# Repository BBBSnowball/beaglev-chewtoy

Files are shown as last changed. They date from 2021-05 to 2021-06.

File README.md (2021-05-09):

This is a fairly simple little board targetted at the BeagleV, but likely usable for anything that uses a 2x20 pin header.

The board takes the existing 2x20 header and either via a through-hole, or smt, header extends it away from the board
(assuming the connector is on the edge), and rotates it 180deg so if you happen to have a large heat sink, or something
else that's blocking the pins they might still be accessible for hats, etc. Most pre-production beta BeagleV boards have a
large heatsink out of an abundance of caution but this is not required and won't be used for production units.

This fork adds:
- LEDs: They are behind a buffer so the SoC or external device doesn't have to drive their current.
- series resistors: They provide some protection if you accidentally connect two outputs or while the SoC is driving
  the pins during reset. Remove them or use lower values if they impact high speed signals.
- JTAG headers: ARM 10-pin (2.54 mm and 1.27 mm, via ribbon cable), Sipeed RV Debugger (directly plugged into the board)
- a second header for debugging (e.g. attach a hat and a logic analyzer at the same time)
- UART connector
- pullups for I2C

All additional features are optional. Don't place the things that you don't need and you can close the solder jumper
below the series resistors if you don't want those. However, if you don't need any of them, I suggest that you use warthog9's
board: It's half the size and doesn't extend to the sides. Mine sacrifices that for a bit more functionality.

Jumpers:
- enable LEDs
- enable RX/TX on the Sipeed connector
  - You have to disable that if you want to use a different UART adapter, e.g. if you
    have trouble assigning different drivers to the parts of the FT2232H on Windows.
  - If you are on Linux, close the solder jumpers and omit the jumpers.
- connect 3.3V and/or 5V to Sipeed connector (solder jumpers)
  - The adapter doesn't need any reference voltage and it doesn't provide enough current to power the board so you should keep them open.
- swap TDI/TDO on the ARM connectors (solder jumpers)
  - I haven't tested the pinout yet so just in case...
- disconnect GND from pin 9 of the ARM connectors (GNDDetect)
- disconnect 3.3V from pin 1 of the ARM connectors
  - JTAG adapters with level shifters will use this to detect the target voltage.
  - If your adapter tries to power the target via this pin, cut the jumper to avoid that.

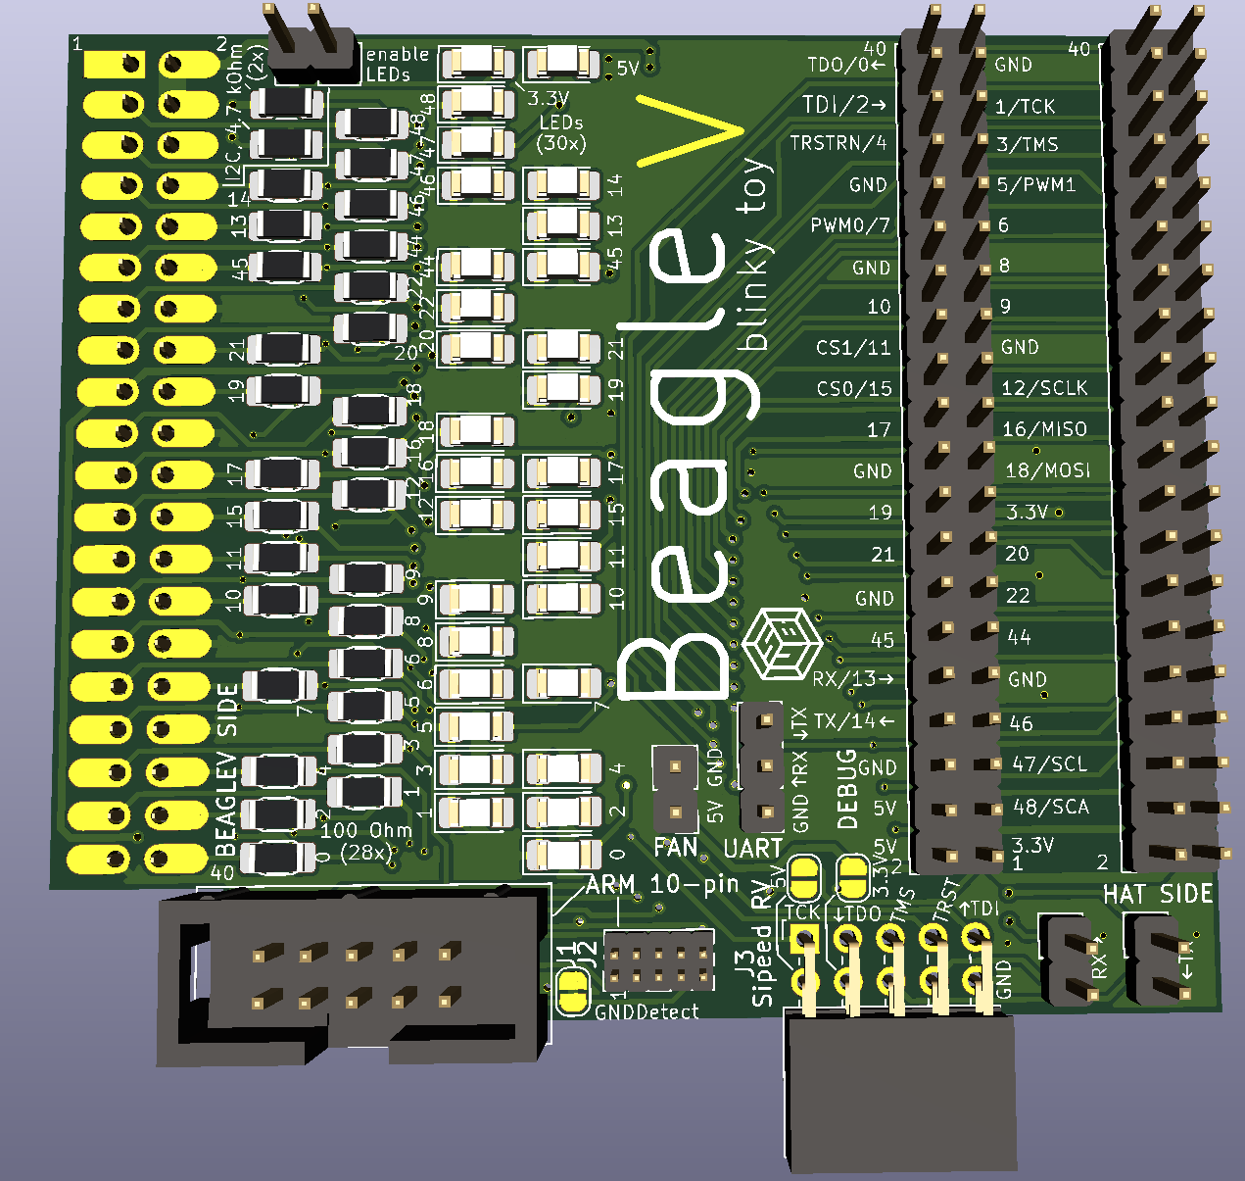
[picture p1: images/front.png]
Front View

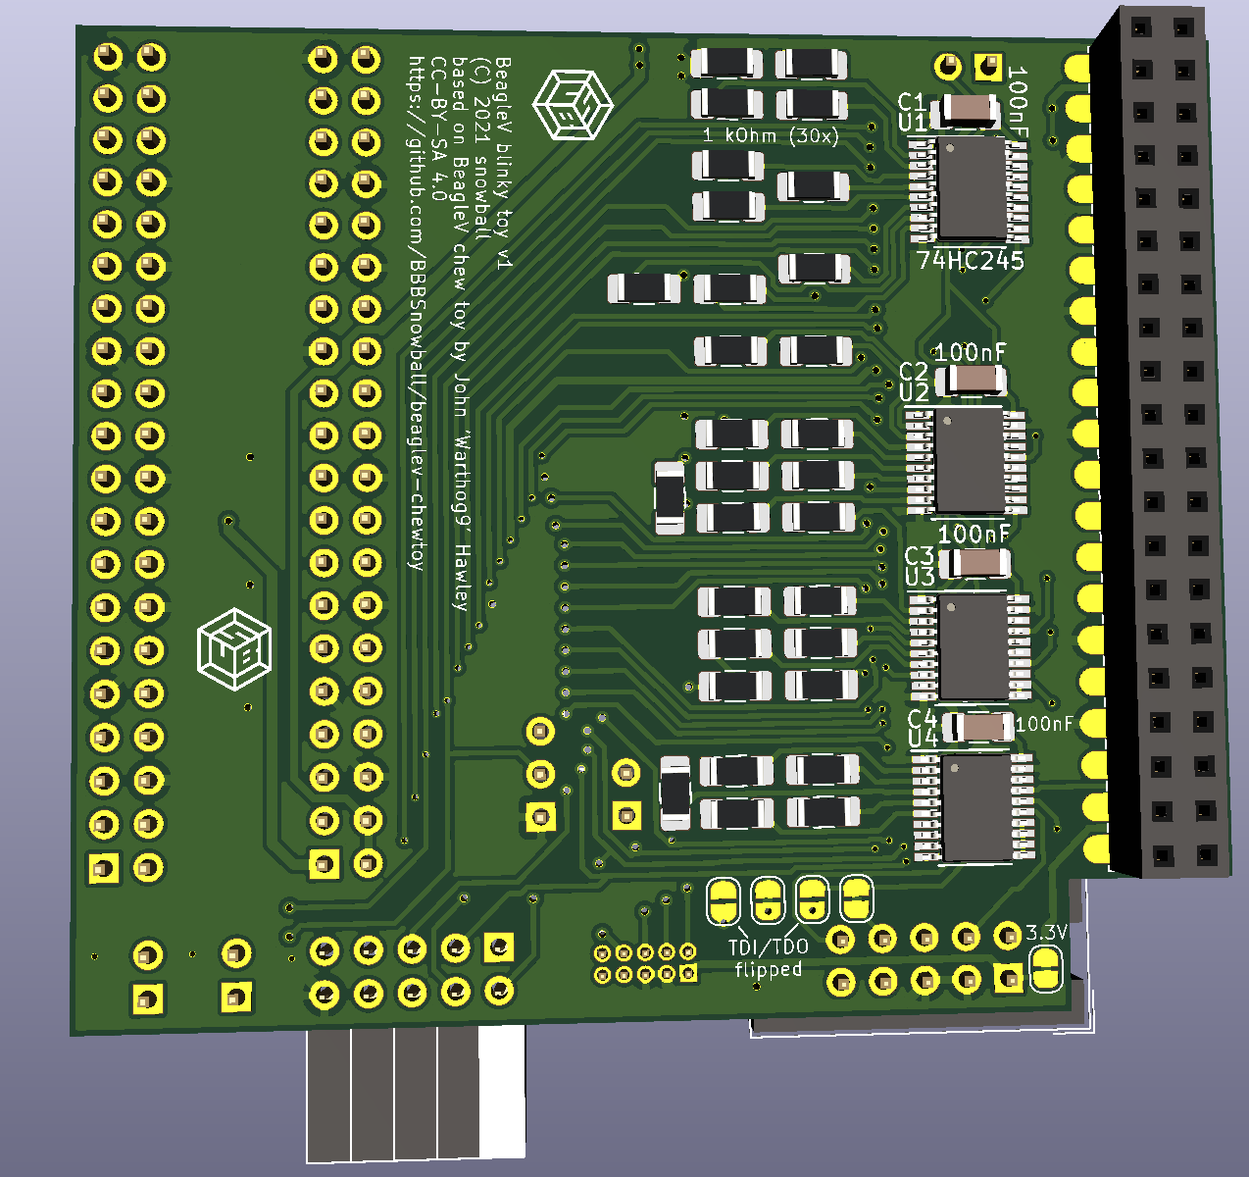
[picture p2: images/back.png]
Back View


# Where to get one built

* OSH Park https://oshpark.com/shared_projects/uNRCdQbW (TODO: update this for the fork)

# License and Copyright
(C) John 'Warthog9' Hawley 2021, snowball 2021
CC-BY-SA 4.0

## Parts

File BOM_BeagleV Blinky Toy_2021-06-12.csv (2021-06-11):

ID | Name | Designator | Footprint | Quantity | Manufacturer Part | Manufacturer | Supplier | Supplier Part | Price
1 | PINHD-2X20 | BEAGLEVSIDE1 | PINSOCKET_2X20_P2.54MM_VERTICAL_THTSMD | 1
2 | 100nF | C1,C2,C3,C4 | C_1206_3216METRIC_PAD1.42X1.75MM_HANDSOLDER | 4
3 | LED | D1,D2,D3,D5,D7,D8,D10,D11,D12,D13,D15,D16,D18,D19,D21,D22,D23,D24,D26,D27,D28,D29,D31,D32,D33,D35,D36,D37,D38,D40 | LED_1206_3216METRIC_PAD1.42X1.75MM_HANDSOLDER | 30
4 | PINHD-1X2 | FAN1 | PINHEADER_1X02_P2.54MM_VERTICAL | 1
5 | LOGO | G,G,G | SUBRAUM_5MM | 3
6 | PINHD-2X20-BIG | DEBUG1,HATSIDE1 | PINHEADER_2X20_P2.54MM_VERTICAL | 2
7 | Conn_02x05_Counter_Clockwise | J1 | IDC-HEADER_2X05_P2.54MM_VERTICAL | 1
8 | Conn_02x05_Counter_Clockwise | J2 | PINHEADER_2X05_P1.27MM_VERTICAL | 1
9 | Conn_02x05_Counter_Clockwise | J3 | PINSOCKET_2X05_P2.54MM_HORIZONTAL | 1
10 | Jumper | JP36,JP38,JP40 | PINHEADER_1X02_P2.54MM_VERTICAL | 3
11 | SolderJumper_2_Bridged | JP1,JP2,JP3,JP4,JP5,JP6,JP7,JP8,JP9,JP10,JP11,JP12,JP13,JP14,JP15,JP17,JP18,JP19,JP20,JP21,JP22,JP23,JP24,JP25,JP26,JP27,JP28,JP29,JP30,JP31,JP34,JP35,JP37,JP39,JP41 | SOLDERJUMPER-2_P1.3MM_OPEN_ROUNDEDPAD1.0X1.5MM | 35
12 | SolderJumper_2_Bridged | JP16,JP32,JP33,JP42 | SOLDERJUMPER-2_P1.3MM_BRIDGED_ROUNDEDPAD1.0X1.5MM | 4
13 | 100R | R1,R2,R3,R4,R5,R6,R7,R8,R9,R10,R11,R12,R13,R14,R15,R16,R17,R18,R19,R20,R21,R22,R23,R24,R25,R26,R27,R28 | R_1206_3216METRIC_PAD1.42X1.75MM_HANDSOLDER | 28
14 | 1k | R31,R32,R33,R35,R36,R37,R38,R39,R40,R41,R42,R43,R44,R45,R46,R47,R48,R49,R50,R51,R52,R53,R54,R55,R56,R57,R59,R60,R63,R64 | R_1206_3216METRIC_PAD1.42X1.75MM_HANDSOLDER | 30
15 | 4k7 | R61,R62 | R_1206_3216METRIC_PAD1.42X1.75MM_HANDSOLDER | 2
16 | 74HC245 | U1,U2,U3,U4 | TSSOP-20_4.4X6.5MM_P0.65MM | 4
17 | PINHD-1X2 | UART1 | PINHEADER_1X03_P2.54MM_VERTICAL | 1

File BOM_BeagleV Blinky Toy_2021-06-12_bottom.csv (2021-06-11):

ID | Name | Designator | Footprint | Quantity | Manufacturer Part | Manufacturer | Supplier | Supplier Part | Price
2 | 100nF | C1,C2,C3,C4 | C_1206_3216METRIC_PAD1.42X1.75MM_HANDSOLDER | 4
14 | 1k | R31,R32,R33,R35,R36,R37,R38,R39,R40,R41,R42,R43,R44,R45,R46,R47,R48,R49,R50,R51,R52,R53,R54,R55,R56,R57,R59,R60,R63,R64 | R_1206_3216METRIC_PAD1.42X1.75MM_HANDSOLDER | 30
16 | 74HC245 | U1,U2,U3,U4 | TSSOP-20_4.4X6.5MM_P0.65MM | 4

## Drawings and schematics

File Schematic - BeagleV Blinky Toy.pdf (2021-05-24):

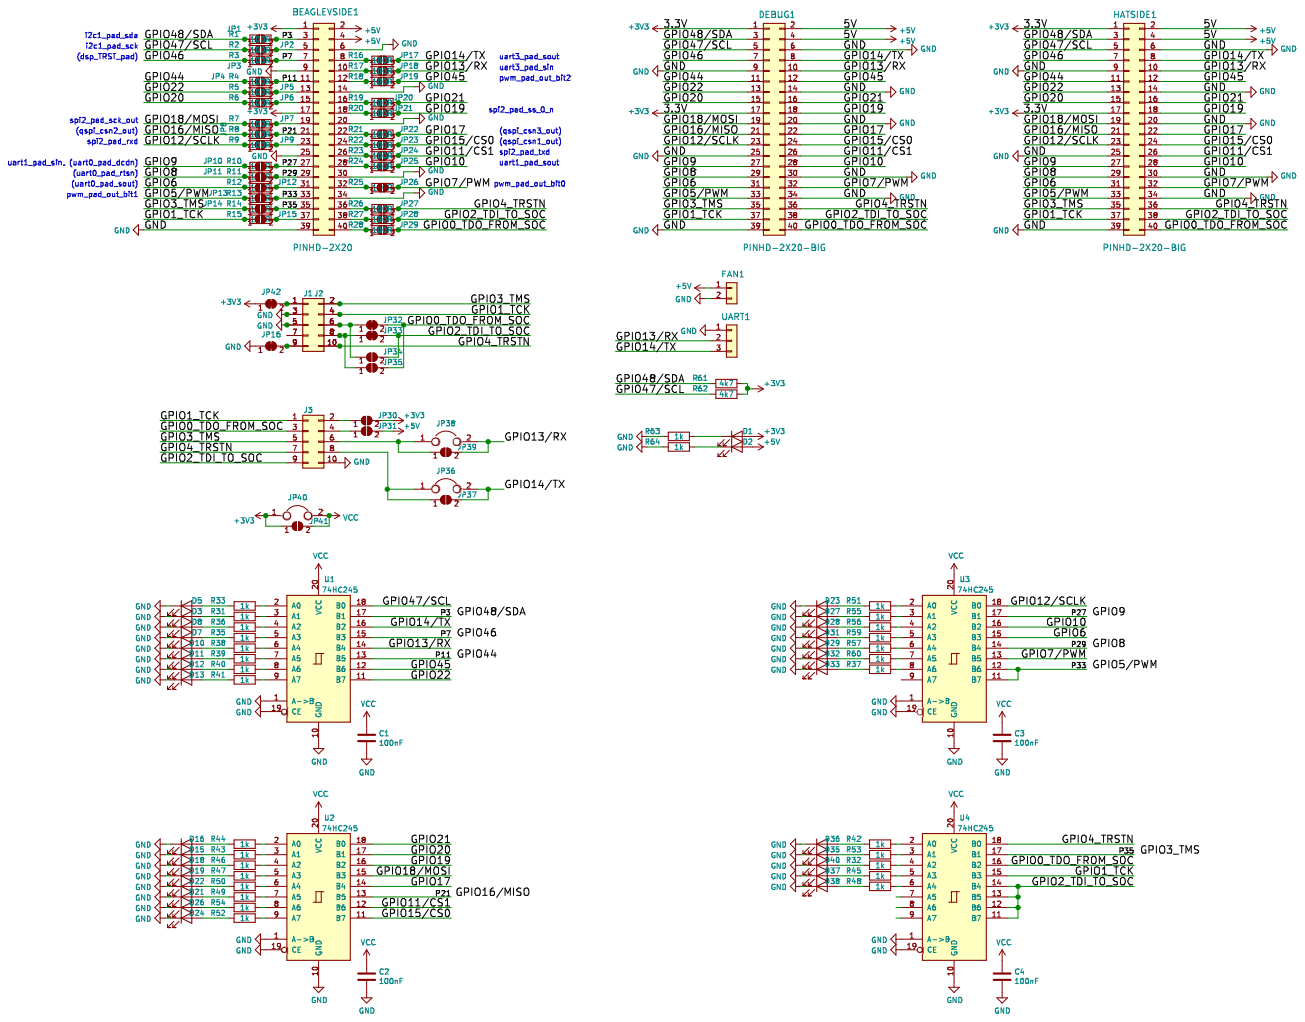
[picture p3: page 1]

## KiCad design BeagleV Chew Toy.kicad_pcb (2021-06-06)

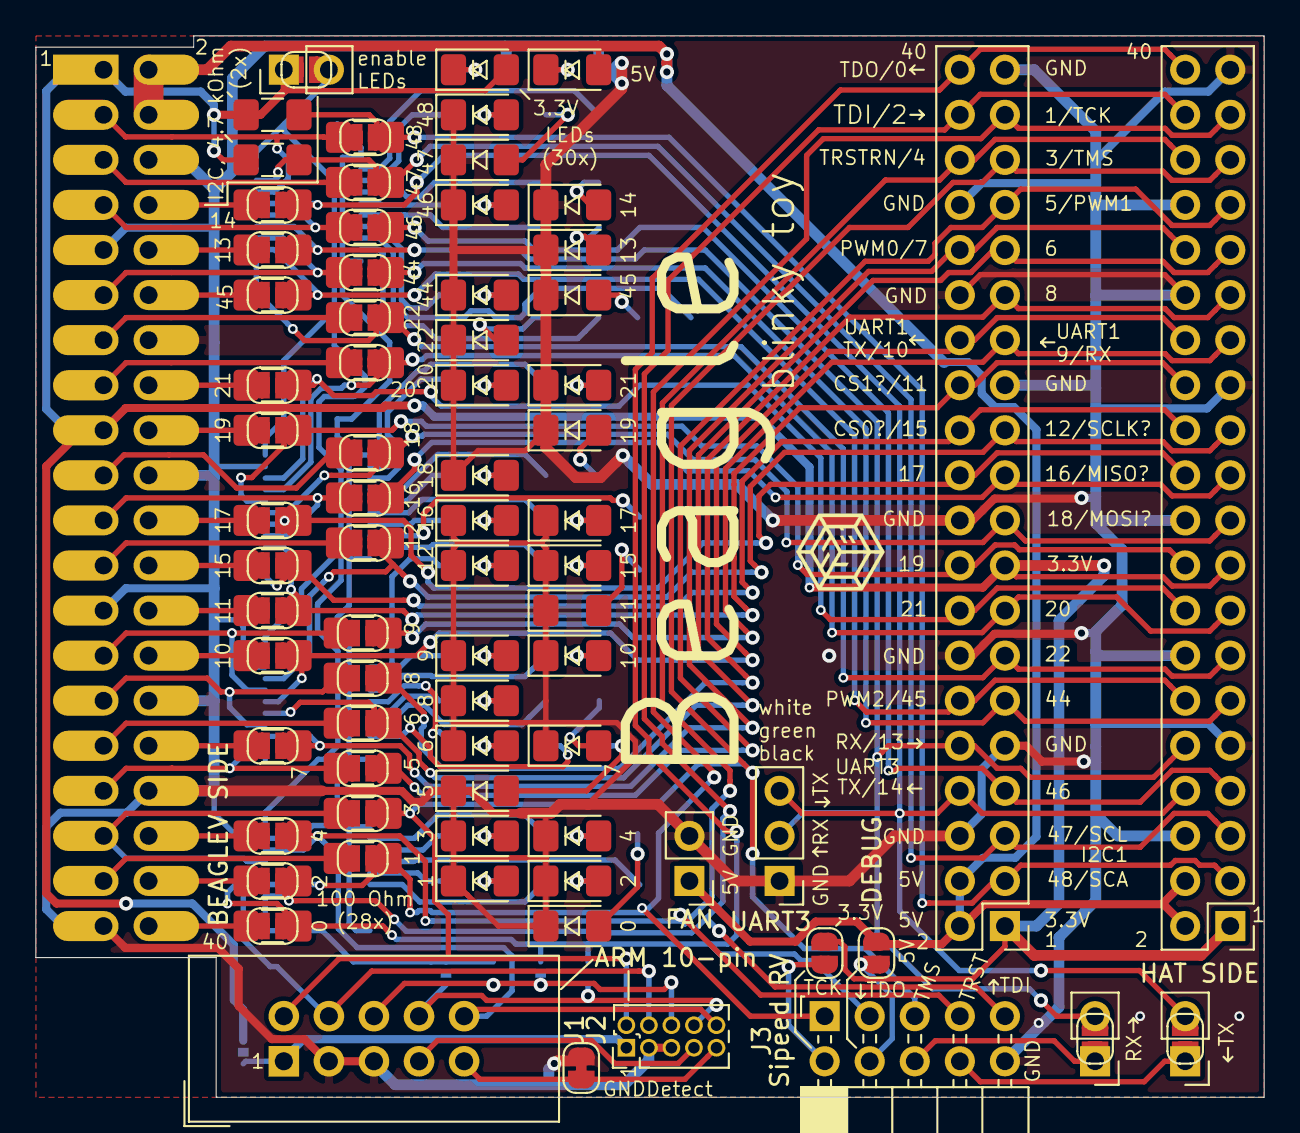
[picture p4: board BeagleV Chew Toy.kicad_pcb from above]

Board: 2 copper layers, 69.2 x 59.8 mm, 148 parts (0 on the bottom side), 127 nets.

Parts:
BEAGLEVSIDE1: PINHD-2X20; PinSocket_2x20_P2.54mm_Vertical_THTSMD
C1, C2, C3, C4: 100nF; C_1206_3216Metric_Pad1.42x1.75mm_HandSolder
D1, D2, D3, D5, D7, D8, D10, D11, D12, D13, D15, D16, D18, D19, D21, D22, D23, D24, D26, D27, D28, D29, D31, D32, D33, D35, D36, D37, D38, D40: LED; LED_1206_3216Metric_Pad1.42x1.75mm_HandSolder
DEBUG1: PINHD-2X20-BIG; PinHeader_2x20_P2.54mm_Vertical
FAN1: PINHD-1X2; PinHeader_1x02_P2.54mm_Vertical
HATSIDE1: PINHD-2X20-BIG; PinHeader_2x20_P2.54mm_Vertical
J1: Conn_02x05_Counter_Clockwise; IDC-Header_2x05_P2.54mm_Vertical
J2: Conn_02x05_Counter_Clockwise; PinHeader_2x05_P1.27mm_Vertical
J3: Conn_02x05_Counter_Clockwise; PinSocket_2x05_P2.54mm_Horizontal
JP1, JP2, JP3, JP4, JP5, JP6, JP7, JP8, JP9, JP10, JP11, JP12, JP13, JP14, JP15, JP17, JP18, JP19, JP20, JP21, JP22, JP23, JP24, JP25, JP26, JP27, JP28, JP29, JP30, JP31, JP34, JP35, JP37, JP39, JP41: SolderJumper_2_Bridged; SolderJumper-2_P1.3mm_Open_RoundedPad1.0x1.5mm
JP16, JP32, JP33, JP42: SolderJumper_2_Bridged; SolderJumper-2_P1.3mm_Bridged_RoundedPad1.0x1.5mm
JP36, JP38, JP40: Jumper; PinHeader_1x02_P2.54mm_Vertical
R1, R2, R3, R4, R5, R6, R7, R8, R9, R10, R11, R12, R13, R14, R15, R16, R17, R18, R19, R20, R21, R22, R23, R24, R25, R26, R27, R28: 100R; R_1206_3216Metric_Pad1.42x1.75mm_HandSolder
R31, R32, R33, R35, R36, R37, R38, R39, R40, R41, R42, R43, R44, R45, R46, R47, R48, R49, R50, R51, R52, R53, R54, R55, R56, R57, R59, R60, R63, R64: 1k; R_1206_3216Metric_Pad1.42x1.75mm_HandSolder
R61, R62: 4k7; R_1206_3216Metric_Pad1.42x1.75mm_HandSolder
U1, U2, U3, U4: 74HC245; TSSOP-20_4.4x6.5mm_P0.65mm
UART1: PINHD-1X2; PinHeader_1x03_P2.54mm_Vertical

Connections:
+3V3: BEAGLEVSIDE1.1, BEAGLEVSIDE1.17, D1.2, DEBUG1.1, DEBUG1.17, HATSIDE1.1, HATSIDE1.17, JP30.2, JP40.1, JP41.1, JP42.1, R61.1, R62.1
+5V: BEAGLEVSIDE1.2, BEAGLEVSIDE1.4, D2.2, DEBUG1.2, DEBUG1.4, FAN1.1, HATSIDE1.2, HATSIDE1.4, JP31.2
/GPIO0_TDO_FROM_SOC: DEBUG1.40, HATSIDE1.40, J3.3, JP29.2, JP32.2, JP35.2, R28.1, U4.16
/GPIO1_TCK: DEBUG1.37, HATSIDE1.37, J1.4, J2.4, J3.1, JP15.1, R15.2, U4.15
/GPIO2_TDI_TO_SOC: DEBUG1.38, HATSIDE1.38, J3.9, JP28.2, JP33.2, JP34.2, R27.1, U4.11, U4.12, U4.13, U4.14
/GPIO3_TMS: DEBUG1.35, HATSIDE1.35, J1.2, J2.2, J3.5, JP14.1, R14.2
/GPIO4_TRSTN: DEBUG1.36, HATSIDE1.36, J1.10, J2.10, J3.7, JP27.2, R26.1, U4.18
/GPIO5/PWM: DEBUG1.33, HATSIDE1.33, JP13.1, R13.2
/GPIO6: DEBUG1.31, HATSIDE1.31, JP12.1, R12.2, U3.15
/GPIO7/PWM: DEBUG1.32, HATSIDE1.32, JP26.2, R25.1, U3.13
/GPIO8: DEBUG1.29, HATSIDE1.29, JP11.1, R11.2
/GPIO9: DEBUG1.27, HATSIDE1.27, JP10.1, R10.2
/GPIO10: DEBUG1.28, HATSIDE1.28, JP25.2, R24.1, U3.16
/GPIO11/CS1: DEBUG1.26, HATSIDE1.26, JP24.2, R23.1, U2.12
/GPIO12/SCLK: DEBUG1.23, HATSIDE1.23, JP9.1, R9.2, U3.18
/GPIO13/RX: DEBUG1.10, HATSIDE1.10, JP18.2, JP38.2, JP39.2, R17.1, U1.14, UART1.2
/GPIO14/TX: DEBUG1.8, HATSIDE1.8, JP17.2, JP36.2, JP37.2, R16.1, U1.16, UART1.3
/GPIO15/CS0: DEBUG1.24, HATSIDE1.24, JP23.2, R22.1, U2.11
/GPIO16/MISO: DEBUG1.21, HATSIDE1.21, JP8.1, R8.2
/GPIO17: DEBUG1.22, HATSIDE1.22, JP22.2, R21.1, U2.14
/GPIO18/MOSI: DEBUG1.19, HATSIDE1.19, JP7.1, R7.2, U2.15
/GPIO19: DEBUG1.18, HATSIDE1.18, JP21.2, R20.1, U2.16
/GPIO20: DEBUG1.15, HATSIDE1.15, JP6.1, R6.2, U2.17
/GPIO21: DEBUG1.16, HATSIDE1.16, JP20.2, R19.1, U2.18
/GPIO22: DEBUG1.13, HATSIDE1.13, JP5.1, R5.2, U1.11
/GPIO44: DEBUG1.11, HATSIDE1.11, JP4.1, R4.2
/GPIO45: DEBUG1.12, HATSIDE1.12, JP19.2, R18.1, U1.12
/GPIO46: DEBUG1.7, HATSIDE1.7, JP3.1, R3.2
/GPIO47/SCL: DEBUG1.5, HATSIDE1.5, JP2.1, R2.2, R62.2, U1.18
/GPIO48/SDA: DEBUG1.3, HATSIDE1.3, JP1.1, R1.2, R61.2
/P3: BEAGLEVSIDE1.3, JP1.2, R1.1, U1.17
/P7: BEAGLEVSIDE1.7, JP3.2, R3.1, U1.15
/P11: BEAGLEVSIDE1.11, JP4.2, R4.1, U1.13
/P21: BEAGLEVSIDE1.21, JP8.2, R8.1, U2.13
/P27: BEAGLEVSIDE1.27, JP10.2, R10.1, U3.17
/P29: BEAGLEVSIDE1.29, JP11.2, R11.1, U3.14
/P33: BEAGLEVSIDE1.33, JP13.2, R13.1, U3.11, U3.12
/P35: BEAGLEVSIDE1.35, JP14.2, R14.1, U4.17
GND: BEAGLEVSIDE1.6, BEAGLEVSIDE1.9, BEAGLEVSIDE1.14, BEAGLEVSIDE1.20, BEAGLEVSIDE1.25, BEAGLEVSIDE1.30, BEAGLEVSIDE1.34, BEAGLEVSIDE1.39, C1.2, C2.2, C3.2, C4.2, D3.1, D5.1, D7.1, D8.1, D10.1, D11.1, D12.1, D13.1, D15.1, D16.1, D18.1, D19.1, D21.1, D22.1, D23.1, D24.1, D26.1, D27.1, D28.1, D29.1, D31.1, D32.1, D33.1, D35.1, D36.1, D37.1, D38.1, D40.1, DEBUG1.6, DEBUG1.9, DEBUG1.14, DEBUG1.20, DEBUG1.25, DEBUG1.30, DEBUG1.34, DEBUG1.39, FAN1.2, HATSIDE1.6, HATSIDE1.9, HATSIDE1.14, HATSIDE1.20, HATSIDE1.25, HATSIDE1.30, HATSIDE1.34, HATSIDE1.39, J1.3, J1.5, J2.3, J2.5, J3.10, JP16.1, R63.2, R64.2, U1.1, U1.10, U1.19, U2.1, U2.10, U2.19, U3.1, U3.10, U3.19, U4.1, U4.10, U4.19, UART1.1
unnamed: BEAGLEVSIDE1.5, JP2.2, R2.1
unnamed: BEAGLEVSIDE1.8, JP17.1, R16.2
unnamed: BEAGLEVSIDE1.10, JP18.1, R17.2
unnamed: BEAGLEVSIDE1.12, JP19.1, R18.2
unnamed: BEAGLEVSIDE1.13, JP5.2, R5.1
unnamed: BEAGLEVSIDE1.15, JP6.2, R6.1
unnamed: BEAGLEVSIDE1.16, JP20.1, R19.2
unnamed: BEAGLEVSIDE1.18, JP21.1, R20.2
unnamed: BEAGLEVSIDE1.19, JP7.2, R7.1
unnamed: BEAGLEVSIDE1.22, JP22.1, R21.2
unnamed: BEAGLEVSIDE1.23, JP9.2, R9.1
unnamed: BEAGLEVSIDE1.24, JP23.1, R22.2
unnamed: BEAGLEVSIDE1.26, JP24.1, R23.2
unnamed: BEAGLEVSIDE1.28, JP25.1, R24.2
unnamed: BEAGLEVSIDE1.31, JP12.2, R12.1
unnamed: BEAGLEVSIDE1.32, JP26.1, R25.2
unnamed: BEAGLEVSIDE1.36, JP27.1, R26.2
unnamed: BEAGLEVSIDE1.37, JP15.2, R15.1
unnamed: BEAGLEVSIDE1.38, JP28.1, R27.2
unnamed: BEAGLEVSIDE1.40, JP29.1, R28.2
unnamed: D1.1, R63.1
unnamed: D2.1, R64.1
unnamed: D3.2, R31.2
unnamed: D5.2, R33.2
unnamed: D7.2, R35.2
unnamed: D8.2, R36.2
unnamed: D10.2, R38.2
unnamed: D11.2, R39.2
unnamed: D12.2, R40.2
unnamed: D13.2, R41.2
unnamed: D15.2, R43.2
unnamed: D16.2, R44.2
unnamed: D18.2, R46.2
unnamed: D19.2, R47.2
unnamed: D21.2, R49.2
unnamed: D22.2, R50.2
unnamed: D23.2, R51.2
unnamed: D24.2, R52.2
unnamed: D26.2, R54.2
unnamed: D27.2, R55.2
unnamed: D28.2, R56.2
unnamed: D29.2, R57.2
unnamed: D31.2, R59.2
unnamed: D32.2, R60.2
unnamed: D33.2, R37.2
unnamed: D35.2, R53.2
unnamed: D36.2, R42.2
unnamed: D37.2, R45.2
unnamed: D38.2, R48.2
unnamed: D40.2, R32.2
unnamed: J1.1, J2.1, JP42.2
unnamed: J1.6, J2.6, JP32.1, JP34.1
unnamed: J1.7, J2.7
unnamed: J1.8, J2.8, JP33.1, JP35.1
unnamed: J1.9, J2.9, JP16.2
unnamed: J3.2, JP30.1
unnamed: J3.4, JP31.1
unnamed: J3.6, JP38.1, JP39.1
unnamed: J3.8, JP36.1, JP37.1
unnamed: R31.1, U1.3
unnamed: R32.1, U4.4
unnamed: R33.1, U1.2
unnamed: R35.1, U1.5
unnamed: R36.1, U1.4
unnamed: R37.1, U3.8
unnamed: R38.1, U1.6
unnamed: R39.1, U1.7
unnamed: R40.1, U1.8
unnamed: R41.1, U1.9
unnamed: R42.1, U4.2
unnamed: R43.1, U2.3
unnamed: R44.1, U2.2
unnamed: R45.1, U4.5
unnamed: R46.1, U2.4
unnamed: R47.1, U2.5
unnamed: R48.1, U4.6
unnamed: R49.1, U2.7
unnamed: R50.1, U2.6
unnamed: R51.1, U3.2
unnamed: R52.1, U2.9
unnamed: R53.1, U4.3
unnamed: R54.1, U2.8
unnamed: R55.1, U3.3
unnamed: R56.1, U3.4
unnamed: R57.1, U3.6
unnamed: R59.1, U3.5
unnamed: R60.1, U3.7
VCC: C1.1, C2.1, C3.1, C4.1, JP40.2, JP41.2, U1.20, U2.20, U3.20, U4.20

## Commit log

2021-05-04 import into Kicad
2021-05-04 add PCB, slightly cleaned up
    [BeagleV Chew Toy.kicad_pcb]
2021-05-04 replace connectors
    The footprints aren't the same anyway so let's use the Kicad parts.
    [BeagleV Chew Toy.kicad_pcb, BeagleV Chew Toy.sch]
2021-05-04 add most of the parts that we need
    [BeagleV Chew Toy.kicad_pcb, BeagleV Chew Toy.sch]
2021-05-05 place LEDs and resistors
    [BeagleV Chew Toy.kicad_pcb, BeagleV Chew Toy.sch]
2021-05-05 3/4 of LEDs routed
    [BeagleV Chew Toy.kicad_pcb, BeagleV Chew Toy.sch]
2021-05-05 LEDs done
    [BeagleV Chew Toy.kicad_pcb, BeagleV Chew Toy.sch]
2021-05-05 use elonged pads on Beagle-side header
    [BeagleV Chew Toy.kicad_pcb]
2021-05-05 main part of the PCB is done
    [BeagleV Chew Toy.kicad_pcb, BeagleV Chew Toy.sch]
2021-05-05 small silk improvements
    [BeagleV Chew Toy.kicad_pcb, BeagleV Chew Toy.sch]
2021-05-06 mostly done
    [BeagleV Chew Toy.kicad_pcb]
2021-05-06 rotate text in silk
    Some of it was in a different orientation than the others.
    [BeagleV Chew Toy.kicad_pcb]
2021-05-06 bugfix: lower left corner would have collided with heatsink mount
    [BeagleV Chew Toy.kicad_pcb, BeagleV Chew Toy.sch]
2021-05-06 replace images, remove Eagle files
    [BeagleV Chew Toy.brd, BeagleV Chew Toy.sch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]
2021-05-06 add UART1 and PWM2 to silk screen
    also add the .sch file again...
    [BeagleV Chew Toy.kicad_pcb, BeagleV Chew Toy.sch]
2021-05-06 add interactive BOM
2021-05-09 add wire colors to UART connector
    [BeagleV Chew Toy.kicad_pcb]
2021-05-09 fixup: swap RX/TX on Sipeed connector
    [BeagleV Chew Toy.kicad_pcb, BeagleV Chew Toy.sch]
2021-05-12 add questionmark to SPI pins in silk, generate gerbers
    [BeagleV Chew Toy-B_Mask.gbr, BeagleV Chew Toy-B_Paste.gbr, BeagleV Chew Toy-B_SilkS.gbr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]
2021-05-12 OSHPark needs different naming for the gerber layers
    [BeagleV Chew Toy-B_Paste.gbr, BeagleV Chew Toy-Bottom.gbl, BeagleV Chew Toy-F_Paste.gbr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]
2021-05-24 update schematic PDF and interactive BOM
2021-06-06 fix two small issues
    - PCB might collide with a heatsink mount to the right of the Beagle-V side
    connector. If so, the involved materials should be flexible enough to
    "resolve" this with a bit of force. Anyway, we can add a cutout to avoid
    that problem in the first place.
    - Silk is swapped for the 5V and 3.3V solder jumpers near the Sipeed connector.
    Gerbers are updated but IBOM is not because there are hardly any changes.
    [BeagleV Chew Toy-B_Mask.gbs, BeagleV Chew Toy-B_SilkS.gbo, BeagleV Chew Toy-Bottom.gbl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]
2021-06-11 PCBA files for JLC as exported by EasyEDA and fixed for bottom side - only valid for bottom side!
    Check component placement in the online preview before you order.
    [BOM_BeagleV Blinky Toy_2021-06-12.csv, BOM_BeagleV Blinky Toy_2021-06-12_bottom.csv, PickAndPlace_BeagleV Blinky Toy_2021-06-12.csv]

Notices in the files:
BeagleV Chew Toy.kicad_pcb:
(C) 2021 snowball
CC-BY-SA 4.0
